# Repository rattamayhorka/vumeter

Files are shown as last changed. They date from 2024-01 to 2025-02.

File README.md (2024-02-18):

# Vumeter - Tablero con Control de Volumen y Display OLED multimedia 

Vumeter, es un proyecto con el que puedes mostrar en un OLED, información en tiempo real como Artista y Cancíón que se está reproduciendo en Linux, muy parecido a lo que era LCD Smartie, :D

Este script de Python interactúa con reproductores multimedia a traves de D-Bus y formatea la información y la envía al atmega32 que controla la pantalla OLED.

## Por implementar:

- vumetro (30%)
- notificaciónes (0%)

## Software

- [Python 3.x](https://www.python.org/downloads/)
- [Daemonize](https://pypi.org/project/daemonize/)
- [pydbus](https://pypi.org/project/pydbus/)
- [unidecode](https://pypi.org/project/Unidecode/)
- [pamixer](https://man.archlinux.org/man/pamixer.1)
- [playerctld](https://archlinux.org/packages/extra/x86_64/playerctl/)

## Hardware

- NEW-HEAVEN OLED DISPLAY [NHD-0420CW OLED SLIM DISPLAY] (https://newhavendisplay.com/content/specs/NHD-0420CW-AY3.pdf)
- MICROCHIP ATMEGA-32 MICROCONTROLLER [ATMEGA32](https://ww1.microchip.com/downloads/en/DeviceDoc/doc2503.pdf)
- USB SERIAL CONVERTER [USB - SERIAL TTL ](https://www.tostatronic.com/product/convertidor-ttl-pl2303-usb-to-rs232-ttl-converter/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)

## Conexiones: 

#define SCL PB6  
#define SDI PB5  
#define CS PB1  

## Serial interface NHD-0420CW configuration:
BS0 - GND  
BS1 - GND  
BS2 - GND  

## OLED CONNECTIONS  PCB / ATMEGA CONNECTIONS   
1  - VSS              GND  
2  - VDD              VOLTAGE  
3  - REGVDD           VOLTAGE  
4  - D/C              GND  
5  - R/W              GND  
6  - E                GND  
7  - D0 [SCLK]        PB6  
8  - D1 [SDI]         PB5  
9  - D2               GND  
10 - D3               GND  
11 - D4               GND  
12 - D5               GND  
13 - D6               GND  
14 - D7               GND  
15 - CS               PB1  
16 - RES              VOLTAGE  
17 - BS0 [SERIAL]     GND  
18 - BS1 [SERIAL]     GND  
19 - BS2 [SERIAL]     GND  
20 - VSS(FRAMEGROUND) GND

## ENCODER CONNECTIONS / ATMEGA CONNECTIONS   
1  - GND              GND  
2  - VCC              VOLTAGE  
3  - SW               PD4  
4  - DT               PD3  
5  - CLK              PD2  

## Diagrama 

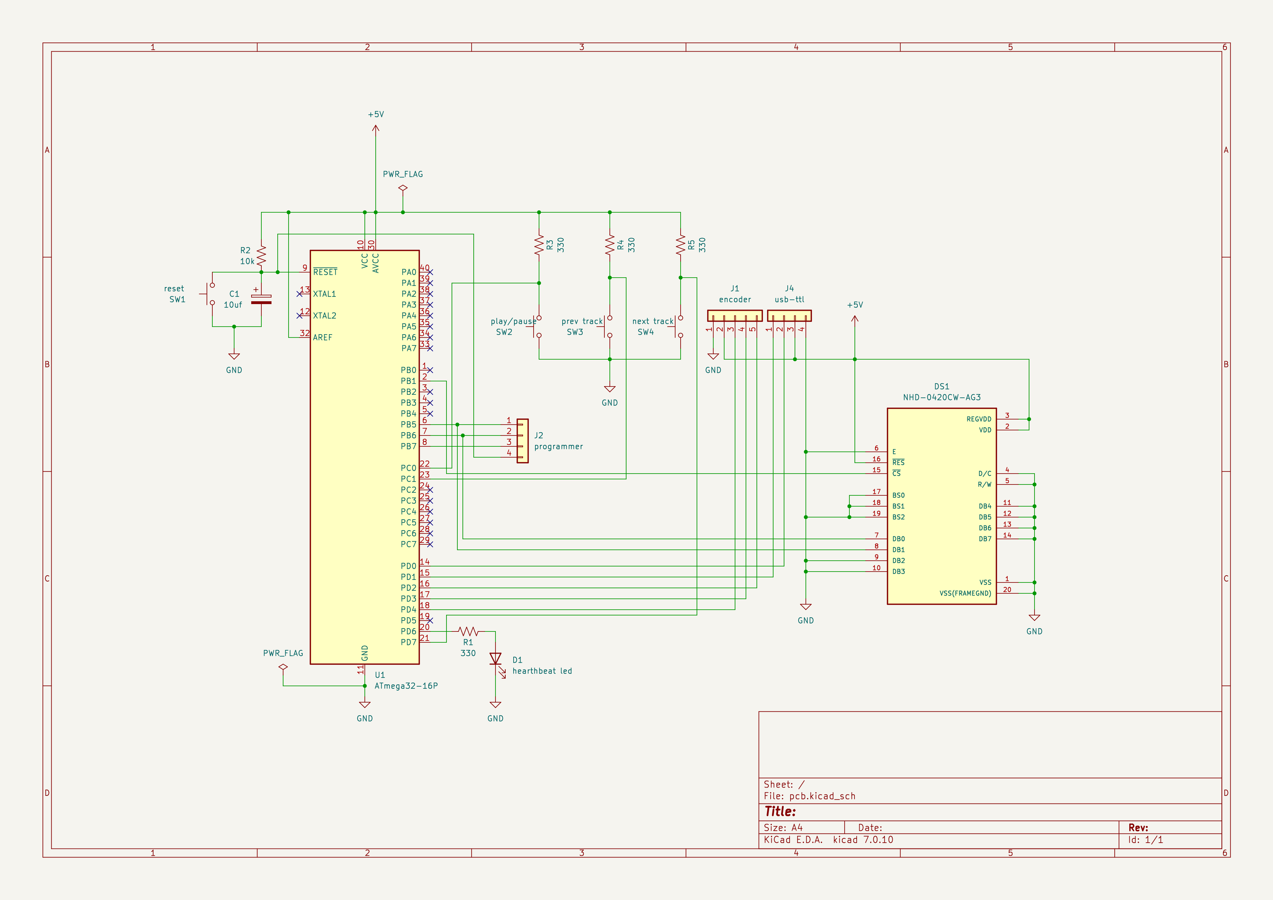
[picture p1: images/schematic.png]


## PCB 

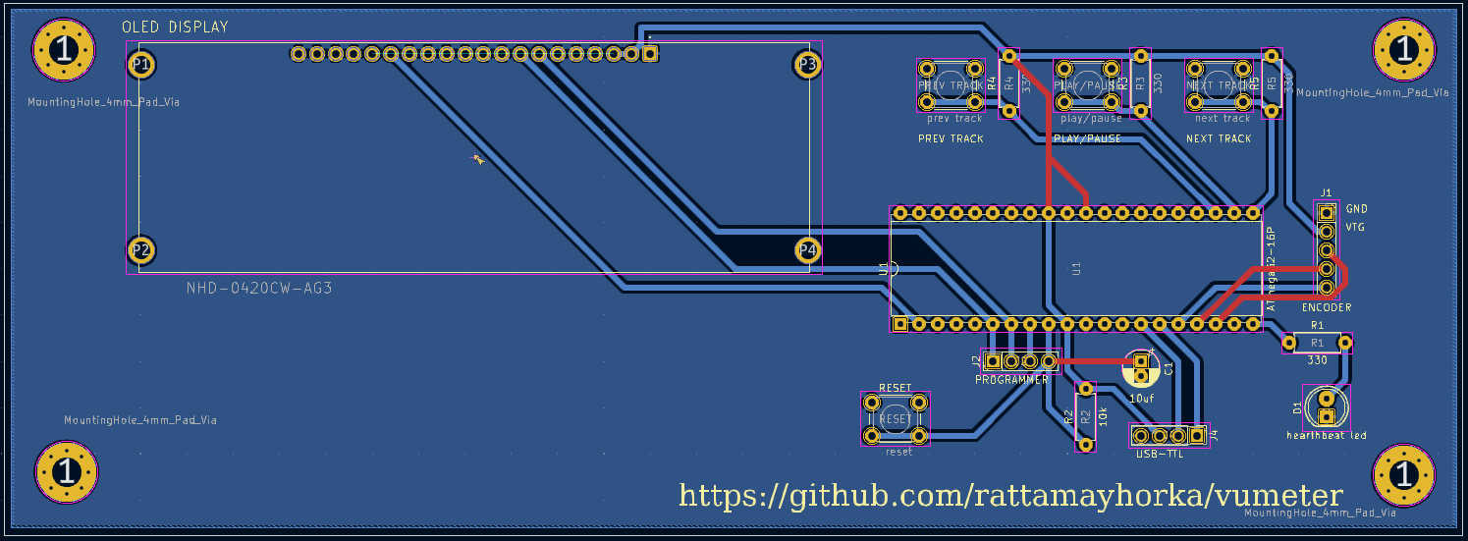
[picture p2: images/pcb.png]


## 3D image 

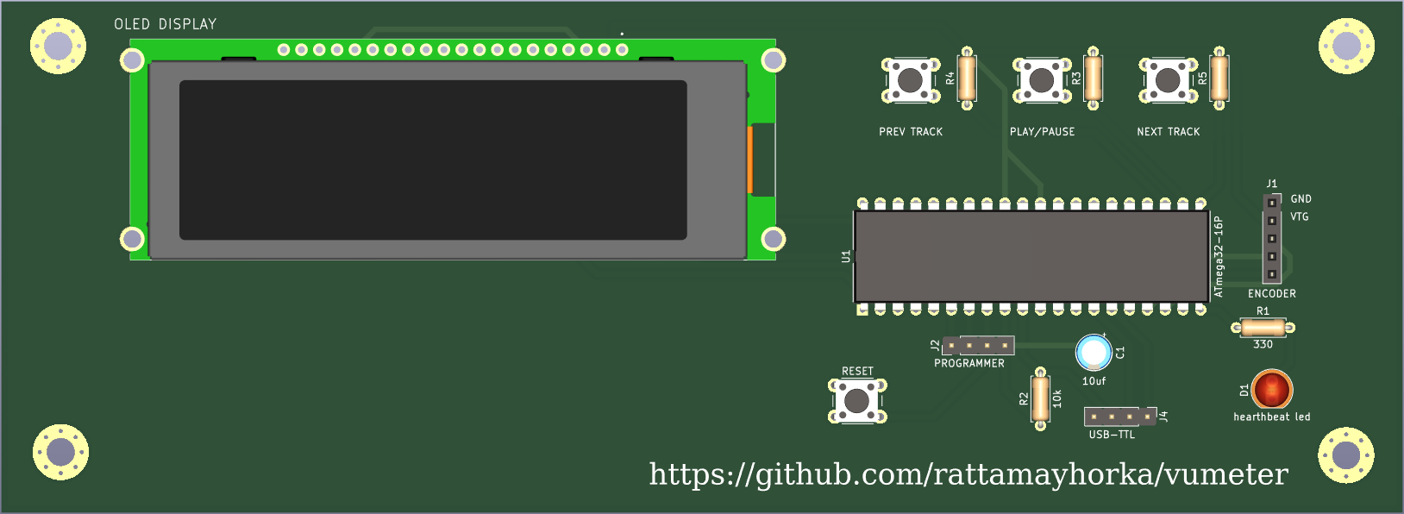
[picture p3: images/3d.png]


## Configuración

Asegúrate de tener todos los requisitos instalados antes de ejecutar el script.

```bash
pip install pydbus unidecode
```
## Uso

Ejecuta el script de la siguiente manera:

```bash
python dbus_data_tx.py
```

El script detectará reproductores multimedia activos y mostrará información sobre la canción en el display OLED. También permite ajustar el volumen mediante un convertidor usb-serial conectado al microcontrolador.

## Notas

- Asegúrate de tener permisos para acceder al puerto serie (`/dev/ttyUSB0` en este caso).
- Ajusta el puerto serie y el baudrate según tu configuración.

## Contribuciones

¡Contribuciones son bienvenidas! Si encuentras errores o mejoras posibles, no dudes en crear un *issue* o enviar un *pull request*.

## Autor

[rattamayhorka]

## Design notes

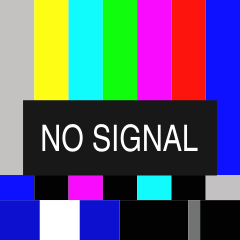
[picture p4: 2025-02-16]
images/nosignal.png

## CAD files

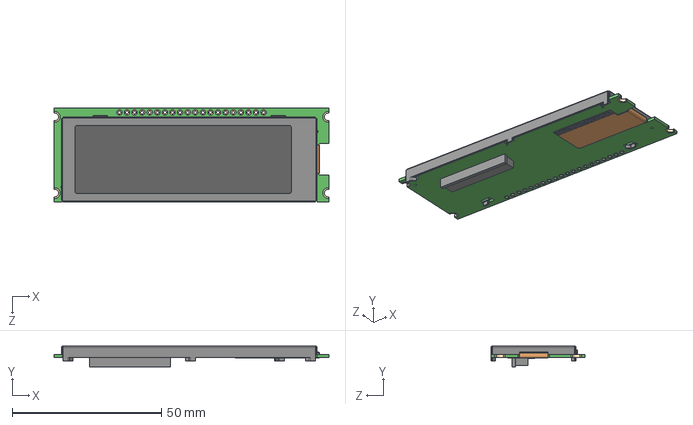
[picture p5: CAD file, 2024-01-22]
hardware/3D_models/NHD-0420CW-AB3--3DModel-STEP-269445.STEP
92.0 x 7.00 x 31.5 mm

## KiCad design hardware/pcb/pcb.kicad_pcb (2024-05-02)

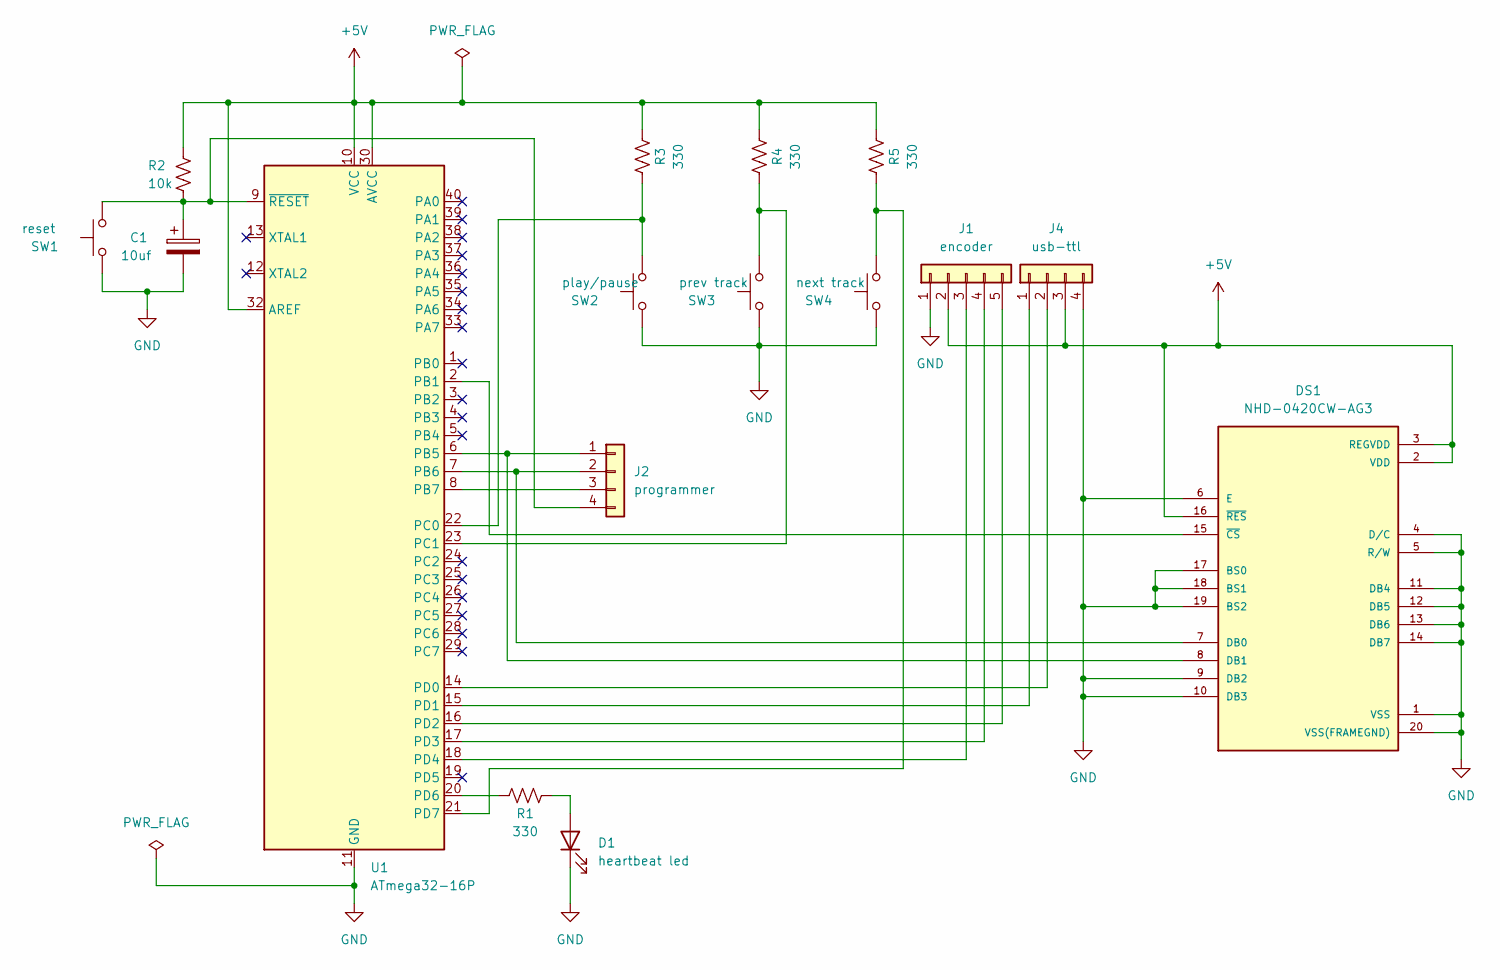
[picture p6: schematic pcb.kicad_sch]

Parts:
C1: 10uf; CP_Radial_D5.0mm_P2.00mm
D1: heartbeat led; LED_D5.0mm
DS1: NHD-0420CW-AG3; NHD_NHD-0420CW-AG3
J1: encoder
J2: programmer; PinHeader_1x04_P2.54mm_Vertical
J4: usb-ttl; PinHeader_1x04_P2.54mm_Vertical
R1, R3, R4, R5: 330; R_Axial_DIN0207_L6.3mm_D2.5mm_P7.62mm_Horizontal
R2: 10k; R_Axial_DIN0207_L6.3mm_D2.5mm_P7.62mm_Horizontal
SW1: reset; SW_PUSH_6mm
SW2: play/pause; SW_PUSH_6mm
SW3: prev track; SW_PUSH_6mm
SW4: next track; SW_PUSH_6mm
U1: ATmega32-16P; DIP-40_W15.24mm

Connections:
+5V: DS1.2 (VDD), DS1.3 (REGVDD), DS1.16 (~RES), J1.2, J4.3, R2.2, R3.2, R4.2, R5.2, U1.10 (VCC), U1.30 (AVCC), U1.32 (AREF)
GND: C1.2, D1.1 (K), DS1.1 (VSS), DS1.4 (D/C), DS1.5 (R/W), DS1.6 (E), DS1.9 (DB2), DS1.10 (DB3), DS1.11 (DB4), DS1.12 (DB5), DS1.13 (DB6), DS1.14 (DB7), DS1.17 (BS0), DS1.18 (BS1), DS1.19 (BS2), DS1.20 (VSS(FRAMEGND)), J1.1, J4.4, SW1.1, SW2.1, SW3.1, SW4.1, U1.11 (GND), U1.31 (GND)
unnamed: D1.2 (A), R1.2
unnamed: DS1.7 (DB0), J2.2, U1.7 (PB6)
unnamed: DS1.8 (DB1), J2.1, U1.6 (PB5)
unnamed: DS1.15 (~CS), U1.2 (PB1)
unnamed: J1.3, U1.18 (PD4)
unnamed: J1.4, U1.17 (PD3)
unnamed: J1.5, U1.16 (PD2)
unnamed: J2.3, U1.8 (PB7)
unnamed: C1.1, J2.4, R2.1, SW1.2, U1.9 (~RESET)
unnamed: J4.1, U1.15 (PD1)
unnamed: J4.2, U1.14 (PD0)
unnamed: R3.1, SW2.2, U1.22 (PC0)
unnamed: R4.1, SW3.2, U1.23 (PC1)
unnamed: R1.1, U1.20 (PD6)
unnamed: R5.1, SW4.2, U1.21 (PD7)

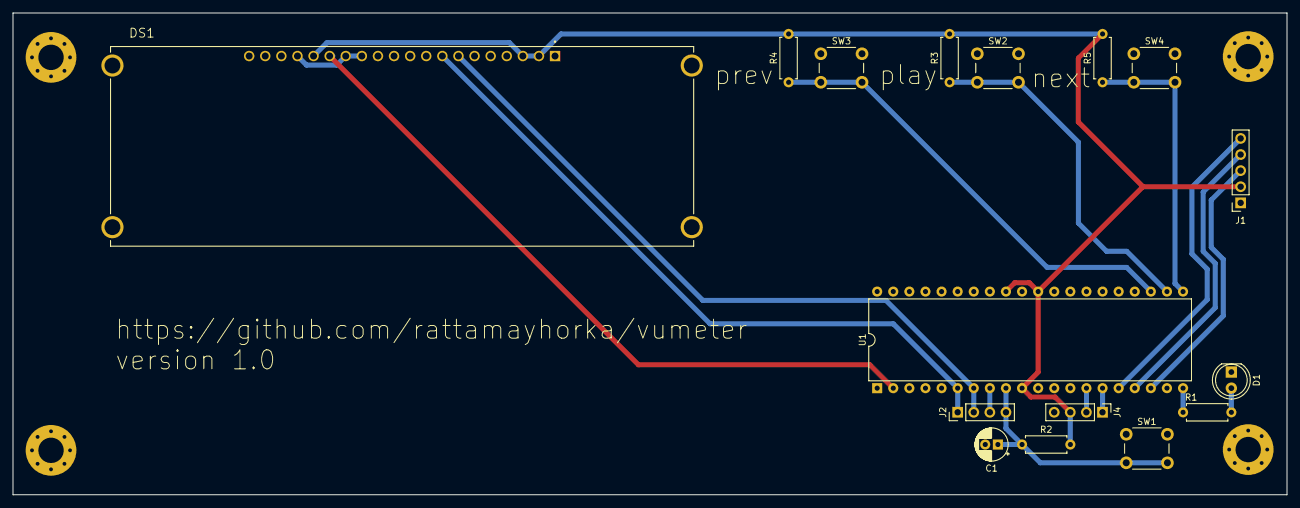
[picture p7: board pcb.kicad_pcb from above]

Board: 2 copper layers, 201.0 x 76.0 mm, 16 parts (0 on the bottom side), 17 nets.

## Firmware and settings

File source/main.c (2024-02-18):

#include <avr/io.h>
#include <util/delay.h>
#include <stdio.h>
#include <avr/interrupt.h>
#include <string.h>
#include "oled.h"

#define BAUD 9600
#define BAUDRATE ((F_CPU)/(BAUD*16UL)-1)
#define USART_BUFFER_SIZE 100
#define NUM_BUFFERS 4 //Número de buffers (artist, title, album)

#define DISPLAY_WIDTH 20
#define DISPLAY_HEIGHT 4

volatile uint8_t interrupt_timer_counter = 0;
volatile uint8_t usart_buffer_index = 0;

volatile uint16_t elapsed_seconds = 0;
volatile uint8_t received_a = 0;
volatile uint8_t timer_expired = 0;

const char buffer_saludo[10] = { 'H','E','C','H','O',' ','P','O','R',':'};
const char buffer_nombre[14] = { 'R','A','T','T','A','M','A','Y','H','O','R','K','A','.'};

static uint8_t switch_next = 0; //next
static uint8_t switch_prev = 0; //prev
static uint8_t switch_play = 0; //play
static uint8_t switch_mute = 0; //mute

char artist_buffer[USART_BUFFER_SIZE];
char title_buffer[USART_BUFFER_SIZE];
char album_buffer[USART_BUFFER_SIZE];
char year_buffer[USART_BUFFER_SIZE];

char *buffers[NUM_BUFFERS] = {artist_buffer, title_buffer, album_buffer,year_buffer};

int current_buffer_index = 0;
int encoder_state;
int last_encoder_state;

int read_encoder(void){
    return ((PIND & (1 << PD2)) >> PD2) | (((PIND & (1 << PD3)) >> PD3) << 1);
}

void usart_init(void){
    UBRRH = (BAUDRATE>>8); // Configurar la velocidad de comunicación en 9600 bps
    UBRRL = BAUDRATE;
    UCSRB = (1 << TXEN) | (1 << RXEN) | (1 << RXCIE);    // Habilitar la transmisión y la recepción UART, así como la interrupción de recepción
    UCSRC = (1 << URSEL) | (1 << UCSZ1) | (1 << UCSZ0); // Configurar el formato de 
}

void usart_transmit(unsigned char data){
    while (!(UCSRA & (1 << UDRE))); // Esperar a que el registro de transmisión esté vacío
    UDR = data; // Enviar el dato
}

void ScrollBuffer(char *buffer, int bufferSize, int j) {
    char first_buffer[21];
    strncpy(first_buffer, buffer, 20);  // Copia los primeros 20 caracteres de buffer a first_buffer
    first_buffer[20] = '\0';  // Asegura que first_buffer sea una cadena válida de C
    OLED_gotoxy(0, 0);

    for (int i = 0; buffer[i] != '\0'; i++) {
        if (buffer[i] == '{') {
            buffer[i] = 0xFD;
        } else if (buffer[i] == '}') {
            buffer[i] = 0xFF;
        } else if (buffer[i] == '[') {
            buffer[i] = 0xFA;
        } else if (buffer[i] == ']') {
            buffer[i] = 0xFC;
        } else if (buffer[i] == 0xC2) {
            buffer[i] = 0x80;
        }
    }

    if (strlen(buffer) <= bufferSize) {
        OLED_gotoxy(0, j);
        OLED_Puts(buffer);
    } else {
        int len = strlen(buffer);
        char temp[21];  // Buffer temporal para el desplazamiento
        for (int i = 0; i <= len - bufferSize; i++) {
            strncpy(temp, buffer + i, bufferSize);  // Copia el siguiente segmento de 20 caracteres
            temp[bufferSize] = '\0';  // Asegura que sea una cadena válida de C
            OLED_gotoxy(0, j);
            OLED_Puts(temp);
            _delay_ms(300);
            
        }
    }

    OLED_gotoxy(0, j);
    OLED_Puts(first_buffer);
}

void PrintBuffer(char *buffer, int j) {
    for (int i = 0; buffer[i] != '\0'; i++) {
        //correccion de caracteres
        if (buffer[i] == '{') {
            buffer[i] = 0xFD;
        } else if (buffer[i] == '}') {
            buffer[i] = 0xFF;
        } else if (buffer[i] == '[') {
            buffer[i] = 0xFA;
        } else if (buffer[i] == ']') {
            buffer[i] = 0xFC;
        } else if (buffer[i] == '_') {
            buffer[i] = 0xC4;
        } else if (buffer[i] == '|') {
            buffer[i] = 0xFE;
        } else if (buffer[i] == 0x17) {
            buffer[i] = 0x80;
        }
    }
    OLED_gotoxy(0, j);
    OLED_Puts(buffer);
}

void OLED_print(void){
    // Borra la pantalla LCD
    OLED_clrscr();
    OLED_gotoxy(0,0);

    PrintBuffer(artist_buffer, 0);
    PrintBuffer(title_buffer, 1);
    PrintBuffer(album_buffer, 2);
    PrintBuffer(year_buffer, 3);
    
    // Reinicia los buffers y el índice
    artist_buffer[0] = '\0';
    title_buffer[0] = '\0';
    album_buffer[0] = '\0';
    year_buffer[0] = '\0';
    usart_buffer_index = 0;
    current_buffer_index = 0;
    OLED_gotoxy(0,0);
}

ISR(USART_RXC_vect) {
    char received_data = UDR; // Leer el carácter recibido

    if (received_data == '\a'){
        received_a = 1; // Se ha recibido '/a'
        timer_expired = 0; // Reinicia el temporizador
        // Borrar la pantalla LCD y reiniciar todos los buffers
        for (int i = 0; i < NUM_BUFFERS; i++){
            buffers[i][0] = '\0'; // Reiniciar el buffer
        }
        usart_buffer_index = 0; // Reiniciar el índice del buffer actual
        current_buffer_index = 0; // Reiniciar el índice del buffer actual
        interrupt_timer_counter = 0; // Reiniciar el contador de tiempo
    }
    else if (received_data == '\n') {
        // Cambiar al siguiente buffer cuando se recibe '\n'
        current_buffer_index++;

        // Si current_buffer_index es igual al número de buffers, significa que se han completado todos
        if (current_buffer_index == NUM_BUFFERS){
            OLED_print();
        }
        else {
            usart_buffer_index = 0; // Reiniciar el índice del buffer actual
        }
    }
    else {
        // Almacenar el carácter en el buffer actual
        char *current_buffer = buffers[current_buffer_index];

        current_buffer[usart_buffer_index] = received_data;
        usart_buffer_index++;

        // Asegurarse de que el buffer no exceda su tamaño máximo
        if (usart_buffer_index >= USART_BUFFER_SIZE){
            usart_buffer_index = USART_BUFFER_SIZE - 1;
        }

        // Terminar la cadena en el buffer para que sea una cadena válida de C
        current_buffer[usart_buffer_index] = '\0';
        interrupt_timer_counter = 0; // Reiniciar el contador de tiempo cuando se recibe un carácter
    }
}

void timer_init(void) {
    //TCCR1B |= (1 << CS11) | (1 << CS10); // Prescaler de 64
    TCCR1B |= (1 << CS10);
    
    TCNT1 = 65536 - 62500; // Valor inicial para 100 milisegundos con prescaler 64
    //TCNT1 = 65472; // (65536 - 64) para 1 Hz
    
    TIMSK |= (1 << TOIE1); // Habilita la interrupción por desbordamiento del temporizador
}

ISR(TIMER1_OVF_vect) {
    static uint16_t led_counter = 0;

    if (led_counter < 1) {
        PORTD |= (1 << PD6); // Enciende el LED
    } else {
        PORTD &= ~(1 << PD6); // Apaga el LED
    }

    led_counter++;
    elapsed_seconds++; // Incrementa el contador de segundos

    if (led_counter == 300) { //300 ~ 2.5s
        led_counter = 0; // Reinicia el contador
    }
    if (elapsed_seconds == 7200 && !received_a && !timer_expired) {
        //Apaga OLED si no hubo conexion a pc en ~1 min. 
        OLED_clrscr();
        OLED_gotoxy(0, 0);
        
        timer_expired = 1; // Marca el temporizador como expirado
    }
}

void boot_splash(void){
    //bloques
    OLED_gotoxy(0,0); 
    for(int i = 0; i < 20; ++i){
        OLED_Data(0x1F);
        _delay_ms(50);    
    }//BLOQUES ANTES DE HECHO POR
    OLED_gotoxy(0,1); 
    for(int i = 0; i < 5; ++i){
        OLED_Data(0x1F);
        _delay_ms(50);    
    }//HECHO POR
    for (int i = 0; i < 10; ++i){
        OLED_Data(buffer_saludo[i]);
        _delay_ms(50);
    }//BLOQUES DESPUES DE HECHO POR
    for(int i = 0; i < 6; ++i){
        OLED_Data(0x1F);
        _delay_ms(50);    
    }//BLOQUES ANTES DE RATTAMAYHORKA
    OLED_gotoxy(0,2);
    for(int i = 0; i < 3; ++i){
        OLED_Data(0x1F);
        _delay_ms(50);    
    }//RATTAMAYHORKA
    for (int i = 0; i < 14; ++i){
        OLED_Data(buffer_nombre[i]);
        _delay_ms(50);
    }//BLOQUES DESPUES DE RATTAMAYHORKA
    for(int i = 0; i < 4; ++i){
        OLED_Data(0x1F);
        _delay_ms(50);    
    }//BLOQUE DE TODA LA LINEA 4
    OLED_gotoxy(0,3); 
    for(int i = 0; i < 20; ++i){
        OLED_Data(0x1F);
        _delay_ms(50);    
    }///BORRADO DE PRIMERA LINEA
    OLED_gotoxy(0,0); 
    for(int i = 0; i < 20; ++i){
        OLED_Data(0x20);
        _delay_ms(50);    
    }//BORRADO ANTES DE HECHO POR
    OLED_gotoxy(0,1); 
    for(int i = 0; i < 5; ++i){
        OLED_Data(0x20);
        _delay_ms(50);    
    }//HECHO POR
    for (int i = 0; i < 10; ++i){
        OLED_Data(buffer_saludo[i]);
        _delay_ms(50);
    }//BORRADO DESPUES DE HEHOC POR
    for(int i = 0; i < 6; ++i){
        OLED_Data(0x20);
        _delay_ms(50);    
    }//BORRADO ANTES DE RATTAMAYHORKA
    OLED_gotoxy(0,2);
    for(int i = 0; i < 3; ++i){
        OLED_Data(0x20);
        _delay_ms(50);    
    }

    for (int i = 0; i < 14; ++i){
        OLED_Data(buffer_nombre[i]);
        _delay_ms(50);
    }

    for(int i = 0; i < 4; ++i){
        OLED_Data(0x20);
        _delay_ms(50);    
    }

    OLED_gotoxy(0,3); 
    for(int i = 0; i < 20; ++i){
        OLED_Data(0x20);
        _delay_ms(50);    
    }

    OLED_gotoxy(0,0); 
    for(int i = 0; i < 20; ++i){
        OLED_Data(0x20);
        _delay_ms(50);    
    }

    OLED_gotoxy(0,1); 
    for(int i = 0; i < 20; ++i){
        OLED_Data(0x20);
        _delay_ms(50);    
    }
    OLED_gotoxy(0,2); 
    for(int i = 0; i < 20; ++i){
        OLED_Data(0x20);
        _delay_ms(50);    
    }
    OLED_gotoxy(0,3); 
    for(int i = 0; i < 20; ++i){
        OLED_Data(0x20);
        _delay_ms(50);    
    }
    OLED_gotoxy(0,0);
}    

void ports_init(void){
    DDRB |= (1 << PB6) | (1 << PB5) | (1 << PB1); //configurar PB1 as CS, PB5 [oled 8] as SDI, pb6 as SCL [oled 7] 

    DDRD |= (1 << PD6); //configurar PD6 como salida LED heartbeat
        
    DDRC &= ~(1 << PD7); // botones multimedia (play)
    DDRC &= ~(1 << PC0); // botones multimedia (next)
    DDRC &= ~(1 << PC1); // botones multimedia (prev)

    DDRD &= ~(1 << PD4);  // PD4 como entrada (SW - encoder)
    DDRD &= ~(1 << PD3);  // PD3 como entrada (DT - encoder)
    DDRD &= ~(1 << PD2);  // PD2 como entrada (CLK - encoder)

    PORTD |= (1 << PD2) | (1 << PD3);  // Habilitar resistencias de pull-up
}

void boot(void){ //funcion de inicio
    ports_init();
    OLED_Init(); // Inicializar OLED
    timer_init();
    boot_splash();
    usart_init(); // Inicializar USART    
    sei();
    PORTD |= (1 << PD6);    
}

int main(void){
    boot();
    
    OLED_gotoxy(0,0); OLED_Puts("Esperando");
    OLED_gotoxy(0,1); OLED_Puts("Conexion a PC...");
    //iniciar timer

    while (1) {
        encoder_state = read_encoder();

        if (encoder_state != last_encoder_state) {
            if ((last_encoder_state == 0b00 && encoder_state == 0b01) || (last_encoder_state == 0b01 && encoder_state == 0b11) ||
    (last_encoder_state == 0b11 && encoder_state == 0b10) || (last_encoder_state == 0b10 && encoder_state == 0b00)) {
                char encoder_command_send[20];
                sprintf(encoder_command_send, "-i 1\n");
                for (int i = 0; encoder_command_send[i] != '\0'; i++) {
                    usart_transmit(encoder_command_send[i]);
                }

            } 
        }
        if ((last_encoder_state == 0b00 && encoder_state == 0b10) || (last_encoder_state == 0b01 && encoder_state == 0b00) ||
    (last_encoder_state == 0b11 && encoder_state == 0b01) || (last_encoder_state == 0b10 && encoder_state == 0b11)) {
                char encoder_command_send[20];
                sprintf(encoder_command_send, "-d 1\n");
                for (int i = 0; encoder_command_send[i] != '\0'; i++) {
                    usart_transmit(encoder_command_send[i]);
                }

        }

        last_encoder_state = encoder_state;
        if (!(PINC & (1 << PC0))) {
            if (switch_next == 0) {
                // El estado del interruptor ha cambiado a presionado
                char encoder_command_send[20];
                sprintf(encoder_command_send, "next\n");
                for (int i = 0; encoder_command_send[i] != '\0'; i++) {
                    usart_transmit(encoder_command_send[i]);
                }
                switch_next = 1;
            }
        } else {
            switch_next = 0;
        }

        if (!(PINC & (1 << PC1))) {
            if (switch_prev == 0) {
                // El estado del interruptor ha cambiado a presionado
                char encoder_command_send[20];
                sprintf(encoder_command_send, "prev\n");
                for (int i = 0; encoder_command_send[i] != '\0'; i++) {
                    usart_transmit(encoder_command_send[i]);
                }
                switch_prev = 1;
            }
        } else {
            switch_prev = 0;
        }

        if (!(PIND & (1 << PD4))) {
            if (switch_mute == 0) {
                // El estado del interruptor ha cambiado a presionado
                char encoder_command_send[20];
                sprintf(encoder_command_send, "-t 1\n");
                for (int i = 0; encoder_command_send[i] != '\0'; i++) {
                    usart_transmit(encoder_command_send[i]);
                }
                switch_mute = 1;
            }
        } else {
            switch_mute = 0;
        }

        if (!(PIND & (1 << PD7))) {
            if (switch_play == 0) {
                // El estado del interruptor ha cambiado a presionado
                char encoder_command_send[20];
                sprintf(encoder_command_send, "play\n");
                for (int i = 0; encoder_command_send[i] != '\0'; i++) {
                    usart_transmit(encoder_command_send[i]);
                }
                switch_play = 1;
            }
        } else {
            switch_play = 0;
        }
        _delay_ms(5);  // Pequeña pausa para evitar lecturas rápidas del encoder
        
    }
}

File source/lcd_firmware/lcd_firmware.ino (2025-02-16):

#include <TFT_eSPI.h>  // Librería para la pantalla ILI9341
#include <SPI.h>

TFT_eSPI tft = TFT_eSPI(); // Inicializa la pantalla
const int screenWidth = 240;  // Ancho de la imagen
const int screenHeight = 240; // Alto de la imagen
const int screenOffsetX = 0;  // Offset horizontal para centrar (320-240)/2

const int adcPin = 34;        // Pin ADC
const int vumeterHeight = 40; // Altura del vúmetro

unsigned long previousMillis = 0;
const long interval = 100;    // Intervalo de actualización del vúmetro (ms)

int currentX = 0; // Posición actual en X para la portada
int currentY = 0; // Posición actual en Y para la portada


// Variables para el valor mínimo y máximo
int minValue = 4095; // Inicialmente el valor máximo posible
int maxValue = 0;    // Inicialmente el valor mínimo posible

void setup() {
  Serial.begin(115200);
  tft.init();
  tft.setRotation(0); // Asegura orientación correcta
  tft.fillScreen(rgbTo565(0, 0, 0));
  pinMode(adcPin, INPUT); // Configura el pin 34 como entrada analógica
}

void loop() {
  unsigned long currentMillis = millis();
  if (currentMillis - previousMillis >= interval) {
    previousMillis = currentMillis;

    // Lectura del ADC en el pin 34
    int adcValue = analogRead(adcPin);
    drawVumeter(adcValue);
  }

  // Recepción de la imagen desde la PC
  if (Serial.available()) {
    for (int x = 0; x < 40; x++) {
      if (Serial.available() >= 2) {
        uint16_t color = (Serial.read() << 8) | Serial.read();
        tft.drawPixel(currentX + screenOffsetX, currentY, color);

        currentX++;
        if (currentX >= screenWidth) {
          currentX = 0;
          currentY++;
          if (currentY >= screenHeight) {
            currentY = 0;
          }
        }
      }
    }
  }
}

/*
void drawVumeter(int value) {
  int numBlocks = 10; // Número de bloques simulando LEDs
  int blockWidth = screenWidth / numBlocks;

  // Actualizar los valores mínimo y máximo
  if (value < minValue) {
    minValue = value; // Si el valor actual es menor que el mínimo, actualiza
  }
  if (value > maxValue) {
    maxValue = value; // Si el valor actual es mayor que el máximo, actualiza
  }

  // Asegurarse de que los valores mínimo y máximo no sean iguales (para evitar divisiones por cero)
  if (maxValue > minValue) {
    // Mapeo de la señal al rango de bloques (0-10)
    int activeBlocks = map(value, minValue, maxValue, 0, numBlocks);

    // Dibuja los bloques del vúmetro según el valor mapeado
    static int lastActiveBlocks = -1;
    if (lastActiveBlocks != activeBlocks) {
      for (int i = 0; i < numBlocks; i++) {
        uint16_t color = (i < activeBlocks) ? getColorForLevel(i, numBlocks) : rgbTo565(50, 50, 50);
        tft.fillRect(i * blockWidth, screenHeight + 20, blockWidth - 2, vumeterHeight, color);
      }
      lastActiveBlocks = activeBlocks;
    }
  }
  // Si los valores mínimo y máximo son iguales, no se hace nada para evitar el error de mapeo
}
*/

void drawVumeter(int value) {
  int numBlocks = 10; // Número de bloques simulando LEDs
  int blockWidth = screenWidth / numBlocks;
  static unsigned long lastResetTime = 0; // Última vez que se reiniciaron los valores

  // Reiniciar min y max cada 6 segundos
  if (millis() - lastResetTime >= 6000) {
    minValue = 4095;
    maxValue = 0;
    lastResetTime = millis(); // Actualizar tiempo del último reinicio
  }

  // Actualizar los valores mínimo y máximo
  if (value < minValue) {
    minValue = value; // Si el valor actual es menor que el mínimo, actualiza
  }
  if (value > maxValue) {
    maxValue = value; // Si el valor actual es mayor que el máximo, actualiza
  }

  // Asegurarse de que los valores mínimo y máximo no sean iguales (para evitar divisiones por cero)
  if (maxValue > minValue) {
    // Mapeo de la señal al rango de bloques (0-10)
    int activeBlocks = map(value, minValue, maxValue, 0, numBlocks);

    // Dibuja los bloques del vúmetro según el valor mapeado
    static int lastActiveBlocks = -1;
    if (lastActiveBlocks != activeBlocks) {
      for (int i = 0; i < numBlocks; i++) {
        uint16_t color = (i < activeBlocks) ? getColorForLevel(i, numBlocks) : rgbTo565(50, 50, 50);
        tft.fillRect(i * blockWidth, screenHeight + 20, blockWidth - 2, vumeterHeight, color);
      }
      lastActiveBlocks = activeBlocks;
    }
  }
}


uint16_t getColorForLevel(int level, int totalLevels) {
  switch (level) {
    case 0: return rgbTo565(0, 0, 255);
    case 1: return rgbTo565(0, 51, 255);
    case 2: return rgbTo565(0, 73, 255);
    case 3: return rgbTo565(0, 102, 255);
    case 4: return rgbTo565(0, 153, 255);
    case 5: return rgbTo565(0, 176, 255);
    case 6: return rgbTo565(0, 204, 255);
    case 7: return rgbTo565(0, 226, 255);
    case 8: return rgbTo565(0, 255, 255);
    case 9: return rgbTo565(0, 255, 192);
    default: return rgbTo565(50, 50, 0);
  }
}

uint16_t rgbTo565(uint8_t r, uint8_t g, uint8_t b) {
  r = 255 - r;
  g = 255 - g;
  b = 255 - b;
  return ((r & 0xF8) << 8) | ((g & 0xFC) << 3) | (b >> 3);
}

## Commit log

2023-08-20 inicio de proyecto
2023-08-23 previo a la implementación del ADC
2023-08-23 pruebas con barras y adc
2023-09-01 se actualiza el software para un lcd de 4 lineas y se corrigen caracteres
    [main.c]
2023-09-04 modifico pines de lcd.h
2023-09-06 agrego los saltos de linea
2023-09-06 envío de caracteres con valor de ADC a python
2023-09-06 haciendo pruebas con control de volumen
2023-09-10 control analogico de volumen funcionando
2023-09-12 agrego opcion de salida de musica con cmus
2023-09-14 separación de implementaciones
2023-09-15 lcd originales de pfleury
2023-09-17 implementación de vector usart para la recepcion con interrupciones
2023-09-18 actualizando lista de archivos
2023-09-20 transmision y recepcion en el mismo programa python
2023-09-24 agrego comandos de inicio y final de mensaje
2023-09-25 guardo en string todo lo que llegue antes de \n
2023-09-26 cada que llega un nuevo mensaje \n, se guarda en un buffer diferente
2023-10-15 add pcb
    [vumeter_pcb.kicad_pcb, vumeter_pcb.kicad_sch]
2023-10-17 agrego 4ta linea con el dato del año
2023-10-17 agregando datos de variables de pc
2023-10-17 agrego variables de pc
2023-10-21 agrego manejo de dbus para videos de youtube
2023-10-21 implementación de notificaciones en dbus
2023-10-22 implementacion de scrolling
2023-10-27 agrego implementacion de strings mayores a 20 caracteres
2023-10-27 manejo por dbus toda la información
2023-10-28 agrego variable artist en la busqueda de youtube
2023-11-03 actualizo información para trabajar con librería pydbus
2023-11-04 control de datos
2023-11-05 agrego opcion de waiting... mientras no hay reproductores activos
2023-11-05 verifico si hay información en title para soporte con bandcamp
2023-11-05 manda información solo cuando cambió de valores
2023-11-05 agrego manejo de reproductor activo como variable
2023-11-08 agrego manejo de status de conexion y desconexion
2023-11-12 correccion de typos
2023-11-12 enchulando el readme
2023-11-19 cambio led de status de PB0 a PD6
2023-11-20 reconfigurando despues de una perdida de fuses
2023-11-20 agrego por default la configuración de fuses de clock interno del atmega
2023-11-21 agrego pantalla de variables de PC
2023-11-29 change adc for encoder
2023-11-29 correcion de bugs
2023-12-03 actualizo archivos para pcb
    [NHD-0420CW.STEP, pcb.kicad_pcb, pcb.kicad_sch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]
2023-12-03 actualizo circuito
    [NHD-0420CW.STEP, pcb.kicad_sch]
2023-12-05 actualización de archivos pcb
    [pcb.kicad_pcb, pcb.kicad_sch]
2023-12-05 actualizando archivos pcb
2023-12-10 actualizo archivos
    [pcb.kicad_sch]
2023-12-13 actualizo manejo de variables y tiempos en programación
2023-12-15 actualizo PCB con switches next, prev, play
    [pcb.kicad_sch]
2023-12-15 actualizacion de pcb
    [pcb.kicad_pcb, pcb.kicad_sch]
2023-12-15 add circuito
2023-12-17 haciendo pruebas con bug
    [pcb.kicad_sch]
2023-12-18 actualizo funciones de scrolling en oled
2023-12-18 implemento el scrolling desde python y no en el microcontrolador
2023-12-19 correccion de muestreo de variables menores de 20 chars
2024-01-18 add oled footprint
    [pcb.kicad_pcb, pcb.kicad_sch]
2024-01-22 actualizacion de archivos con footprint OLED
    [NHD-0420CW-AB3--3DModel-STEP-269445.STEP, pcb.kicad_pcb, pcb.kicad_sch]
2024-01-22 actualizacion de archivos en carpeta source
2024-01-30 actualizacion de manejo de errores
    [dbus_data_tx.py]
2024-02-06 correcciones de impresion de caracteres
2024-02-10 update pcb
    [pcb.kicad_pcb]
2024-02-18 agrego timer de apagado si no hay conexion a pc
    [pcb.kicad_pcb, pcb.kicad_sch]
2024-02-18 actualizo lista de caracteres codificados
2024-05-01 retomando proyecto
    [pcb.kicad_pcb, pcb.kicad_sch]
2024-05-01 add play/pause text
    [pcb.kicad_pcb]
2024-07-11 fix misplaced buttons (play/next)
    [dbus_data_tx.py]
2024-11-04 agrego identificador de usb
2024-11-24 manejo de imagen mpris sino encuentra en last.fm
2025-01-27 modificacion de rotacion por cambio de hardware
2025-02-02 actualizo lcd para mostrar vumeter simulado
2025-02-16 add mic diagram for vumeter
    [mic.kicad_pcb, mic.kicad_sch]
2025-02-16 renamed files
    [pcb.kicad_pcb]
2025-02-16 organizacion de archivos
2025-02-16 add mic amplifier circuit
    [mic.kicad_pcb, mic.kicad_sch]
2026-03-16 mejoro colores y funcionamiento de vumetro
